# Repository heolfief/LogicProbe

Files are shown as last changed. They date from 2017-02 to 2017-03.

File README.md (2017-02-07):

# Logic probe
**Three state logic probe**

This is a NAND based three state logic probe with an optional buzzer.

The three states are : 
* HIGH         --  Green LED
* LOW          --  Red LED
* UNDETERMINED --  Blue LED

The undetermined step is active when the probe can't figure out if the signal probed is high or low (floating), or when the signal is switching quickly between the two (PWM).

The ".sch"(schematics) and ".brd"(board layout) files are in **Autodesk Eagle 8.0** format.

The PCB can be made of a single sided copper board. Components packages are 1206, 0805, SO14 and SOT23-3.

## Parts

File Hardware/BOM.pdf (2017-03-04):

# Logic Probe BOM

Part | Value | Package | Description
IC1 | 74HC00 | SO14 | Quad 2-input NAND gate
Q1 | BC847B | SOT23-3 | NPN transistor
R1 | 4.7k | 1206 | Resistor
R2 | 510 | 0805 | Resistor
R3 | 510 | 0805 | Resistor
R4 | 510 | 0805 | Resistor
R5 | 10k | 0805 | Resistor
C1 | 0.1u | 0805 | Capacitor
C2 | 0.1u | 0805 | Capacitor
LED1 Green | 1206 | LED
LED2 Red | 1206 | LED
LED3 Blue | 1206 | LED
LS1 | BUZZER-PTH | BUZZER-12MM | Buzzer
S1 | pwr_switch | SWITCH_DPDT_SMD_AYZ0202 | Double-Pole, Double-Throw (DPDT) Switch
S2 | buzzer_switch | SWITCH_DPDT_SMD_AYZ0202 | Double-Pole, Double-Throw (DPDT) Switch
BT1 | CR1632 | BATTCON_16MM_PTH | Battery - Single Cell
J1 | GND_connector MOLEX-1X2 | Generic Header-pin, 0.1 inch spaced

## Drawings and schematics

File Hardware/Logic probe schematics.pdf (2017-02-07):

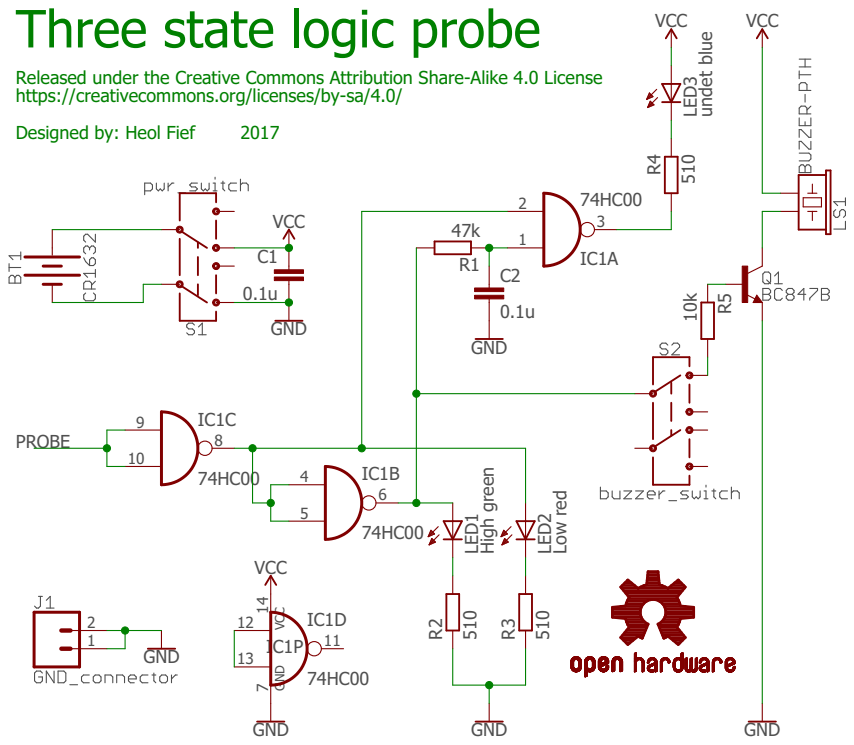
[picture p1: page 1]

Three state logic probe

Released under the Creative Commons Attribution Share-Alike 4.0 License
https://creativecommons.org/licenses/by-sa/4.0/

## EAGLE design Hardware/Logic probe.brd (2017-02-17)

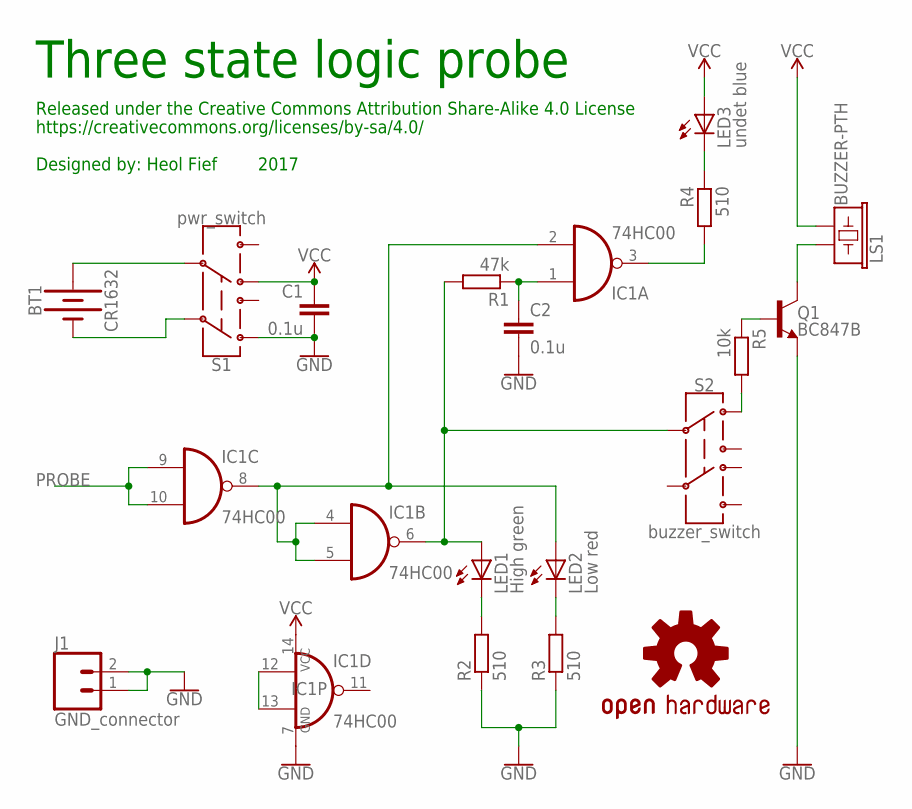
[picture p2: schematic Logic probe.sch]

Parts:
BT1: CR1632; BATTCON_16MM_PTH
C1, C2: 0.1u; C0805
IC1: 74HC00; SO14
J1: GND_connector; MOLEX-1X2
LED1: High green; 1206
LED2: Low red; 1206
LED3: undet blue; 1206
LOGO1: OSHW-LOGOL; OSHW-LOGO-L
LS1: BUZZER-PTH; BUZZER-12MM
Q1: BC847B; SOT23-3
R1: 47k; R1206
R2, R3, R4: 510; R0805
R5: 10k; R0805
S1: pwr_switch; SWITCH_DPDT_SMD_AYZ0202
S2: buzzer_switch; SWITCH_DPDT_SMD_AYZ0202

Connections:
GND: C1.2, C2.2, IC1.7 (GND), J1.1, J1.2, Q1.2 (E), R2.1, R3.1, S1.1
unnamed: LED3.C, R4.2
unnamed: R5.2, S2.1
unnamed: IC1.2 (I1), IC1.4 (I0), IC1.5 (I1), IC1.8 (O), LED2.A
unnamed: Q1.1 (B), R5.1
unnamed: LS1.+ (1), Q1.3 (C)
unnamed: BT1.GND (-), S1.2
unnamed: C2.1, IC1.1 (I0), R1.1
unnamed: LED1.C, R2.2
unnamed: IC1.3 (O), R4.1
unnamed: LED2.C, R3.2
unnamed: BT1.VCC@1 (+), BT1.VCC@2 (+), S1.5
unnamed: IC1.12 (I0), IC1.13 (I1)
unnamed: IC1.6 (O), LED1.A, R1.2, S2.2
PROBE: IC1.9 (I0), IC1.10 (I1)
VCC: C1.1, IC1.14 (VCC), LED3.A, LS1.- (2), S1.4

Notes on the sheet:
Released under the Creative Commons Attribution Share-Alike 4.0 License
https://creativecommons.org/licenses/by-sa/4.0/
Designed by: Heol Fief 2017
Three state logic probe

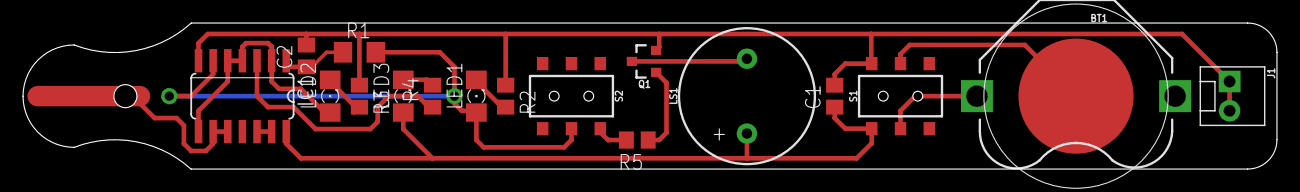
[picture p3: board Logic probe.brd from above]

Board: 2 copper layers, 108.9 x 12.7 mm, 18 parts (0 on the bottom side), 16 nets.

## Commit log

2017-02-04 Add files via upload
    Eagle schematics and board layout files
    [Logic probe.brd, Logic probe.sch]
2017-02-04 Add files via upload
    Schematics PDF
2017-02-04 Add files via upload
    Schematics in PDF format
2017-02-05 Add files via upload
    Add hardware files
    [Logic probe.brd, Logic probe.sch]
2017-02-05 Delete Logic probe schematics.pdf
    moved to hardware folder
2017-02-05 Delete Logic probe.brd
    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
    [Logic probe.brd]
2017-02-05 Delete Logic probe.sch
    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
    [Logic probe.sch]
2017-02-05 Add files via upload
    Add BOM
2017-02-05 Update README.md
    Add hardware description (PCB and packages)
2017-02-07 Update README.md
    Mention about floating and PWM
2017-02-07 Add files via upload
    Fix buzzer circuit
2017-02-17 Add files via upload
    Change battery size & probe lenght
    [Logic probe.brd, Logic probe.sch]
2017-02-17 Add files via upload
    Change battery size

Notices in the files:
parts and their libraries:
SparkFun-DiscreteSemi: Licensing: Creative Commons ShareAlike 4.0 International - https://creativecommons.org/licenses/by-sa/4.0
